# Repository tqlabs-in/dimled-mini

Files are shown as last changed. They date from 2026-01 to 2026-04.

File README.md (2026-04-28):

<p align="center">
  <a href="https://github.com/tqlabs-in/dimled-mini">
    <picture>
      <source srcset="assets/logo-dark.png" media="(prefers-color-scheme: dark)">
      <source srcset="assets/logo-light.png" media="(prefers-color-scheme: light)">
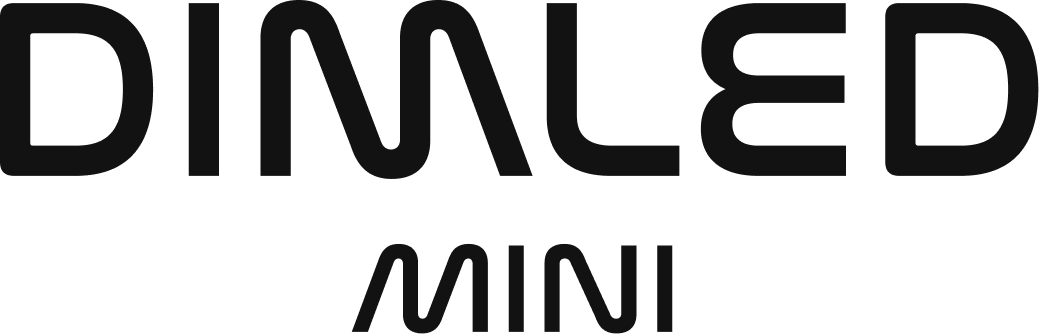
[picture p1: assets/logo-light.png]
DimLED Mini logo
      
    </picture>
  </a>
</p>

<p align="center"><q style="font-style: italic; font-weight: bold;"> Open Source PWM LED Dimmer powered by ESPHome </q></p>
<p align="center">
  
  
</p>

## 😎 Product Photography

<p align="center">
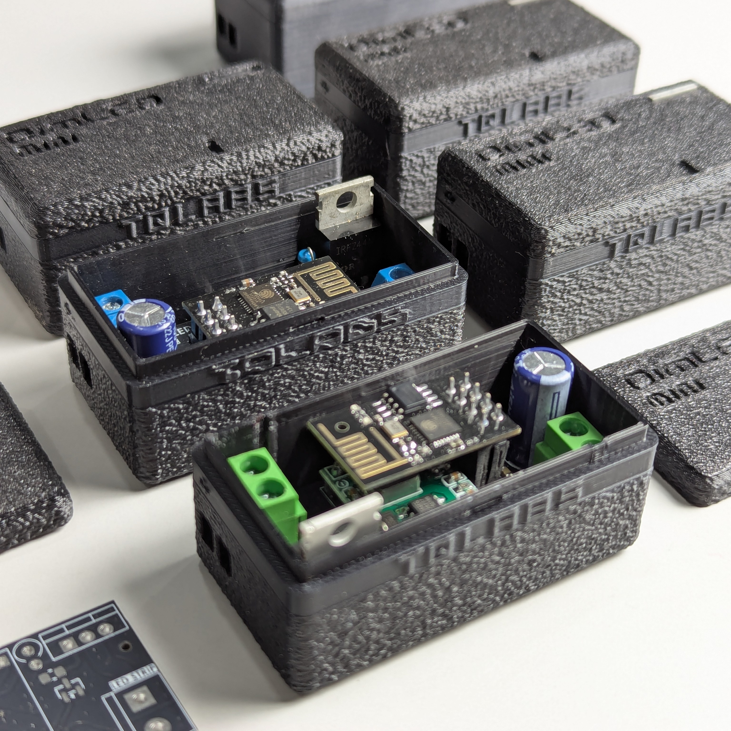
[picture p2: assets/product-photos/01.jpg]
Product Image 1
  
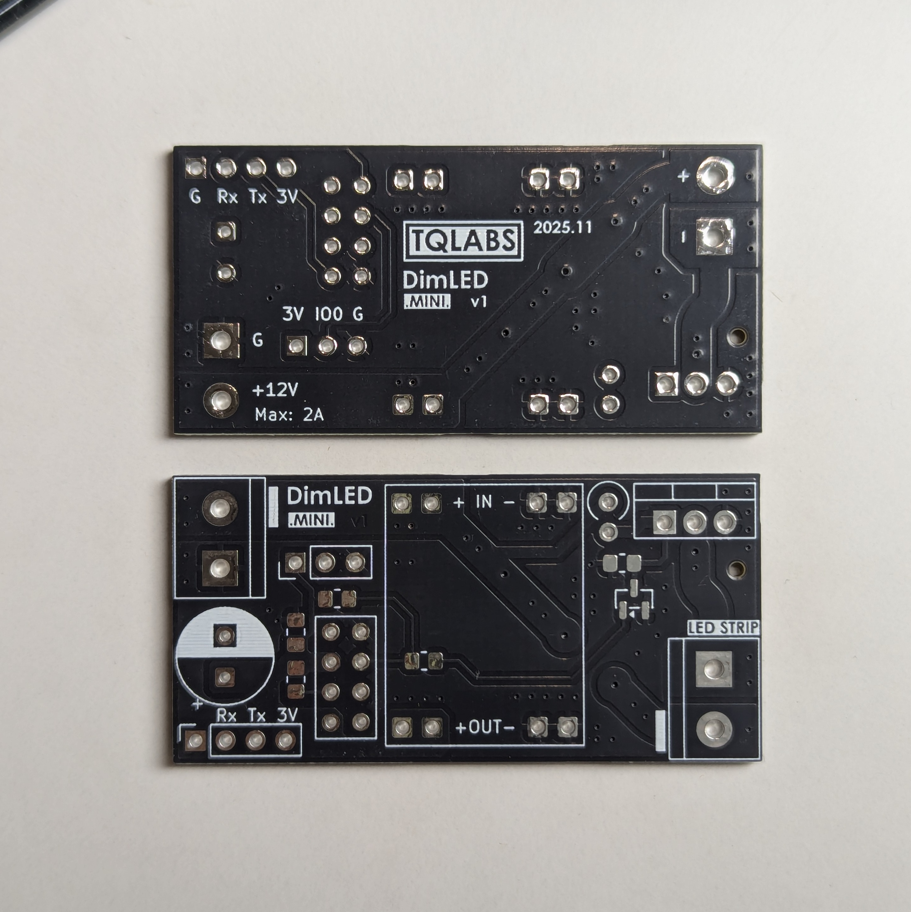
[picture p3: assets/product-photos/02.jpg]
Product Image 2
  
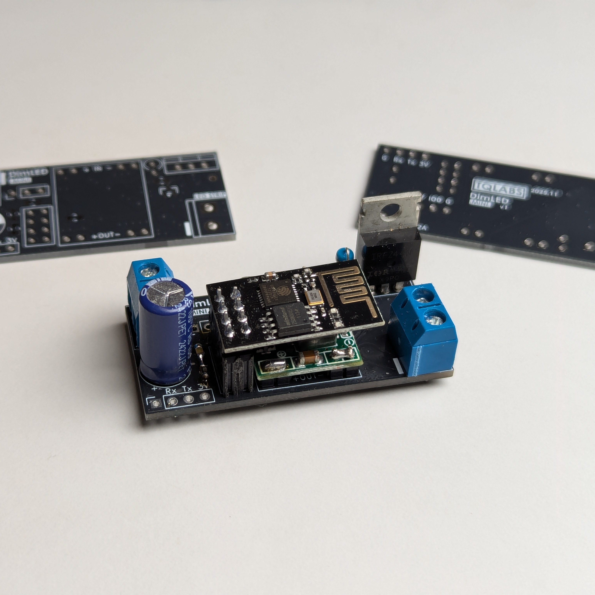
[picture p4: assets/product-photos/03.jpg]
Product Image 3
  
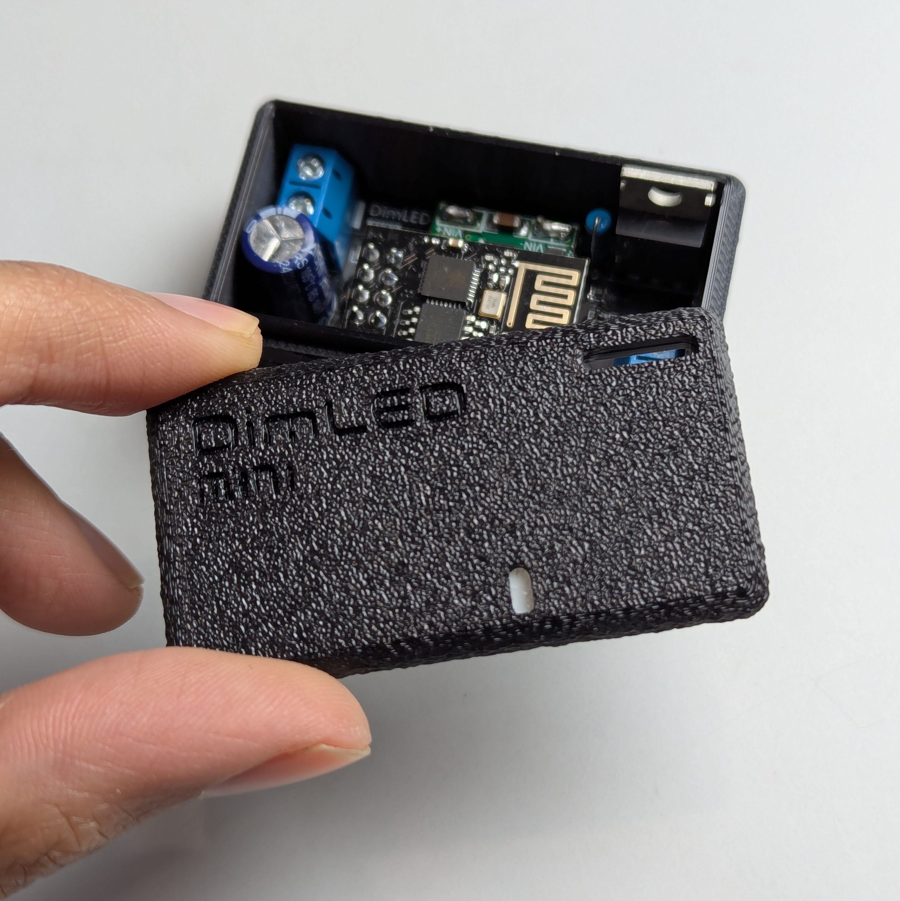
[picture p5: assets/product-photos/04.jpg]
Product Image 4
  
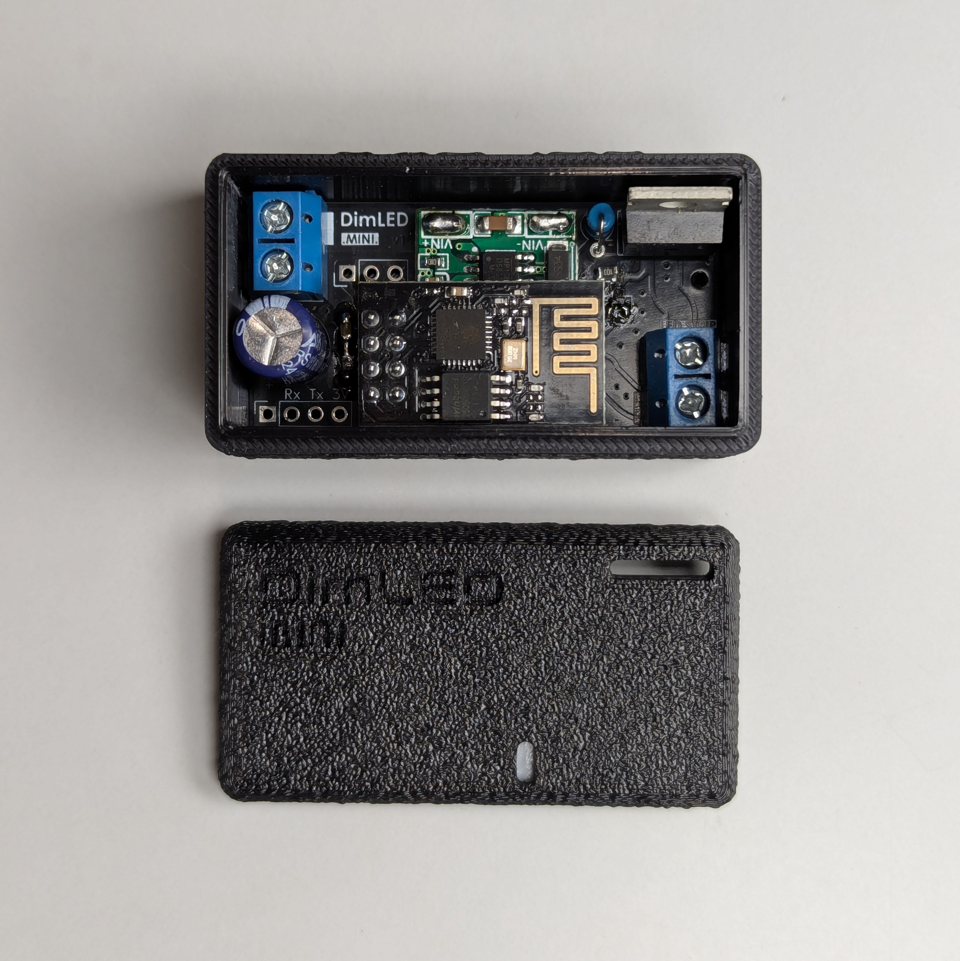
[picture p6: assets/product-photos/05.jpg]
Product Image 5
  
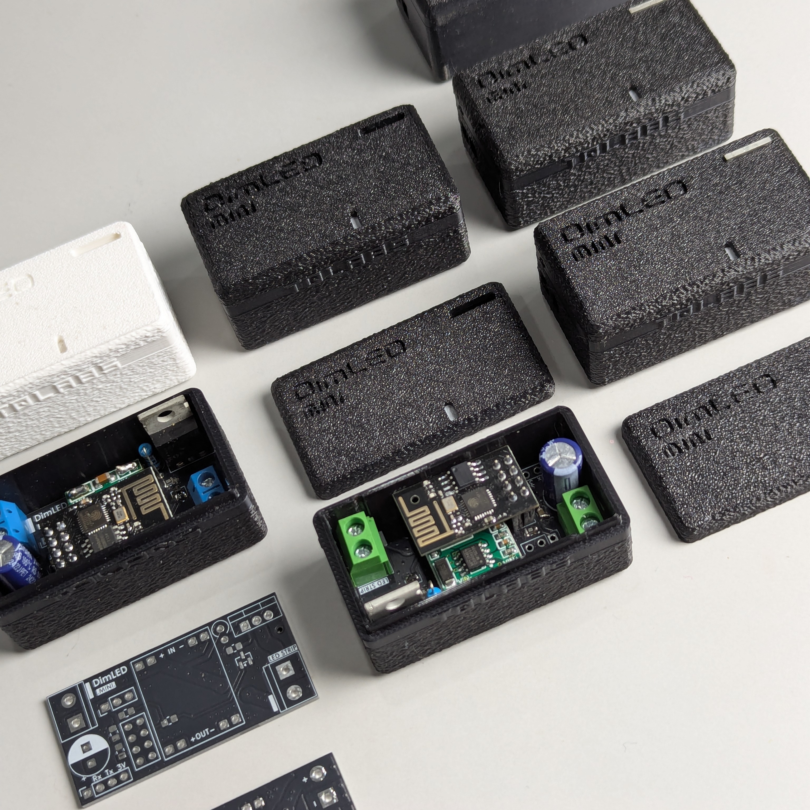
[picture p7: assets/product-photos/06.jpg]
Product Image 6
  
</p>

## 🎰 PCB Renders

<p align="center">
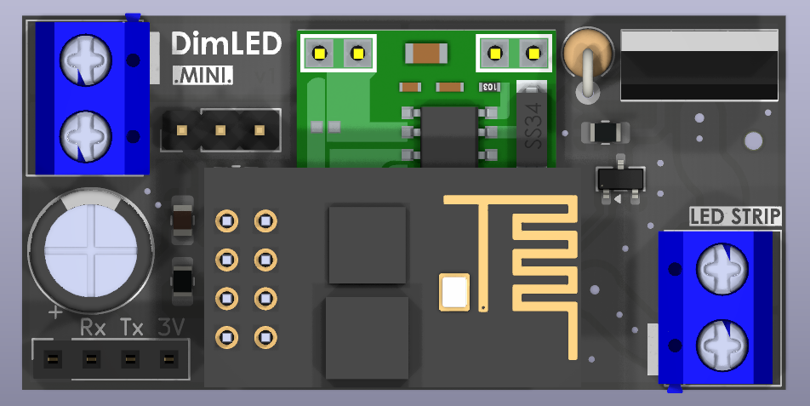
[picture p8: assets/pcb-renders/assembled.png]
PCB Render
  
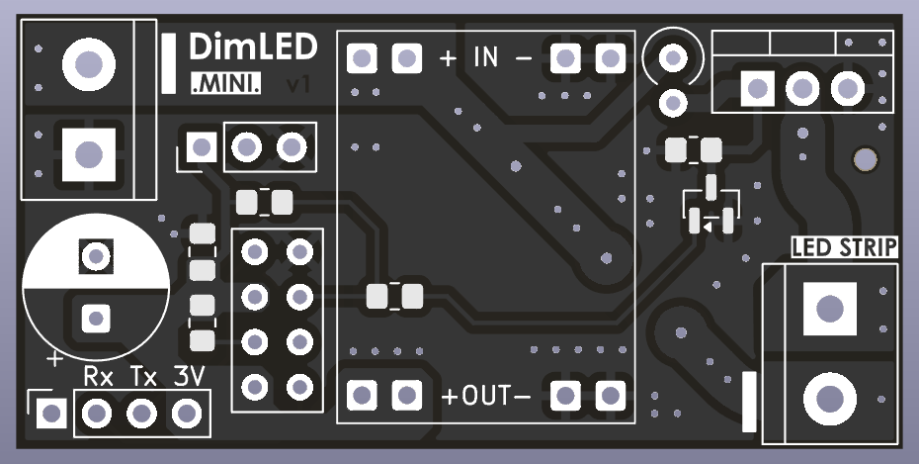
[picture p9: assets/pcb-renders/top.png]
PCB Top Layer
  
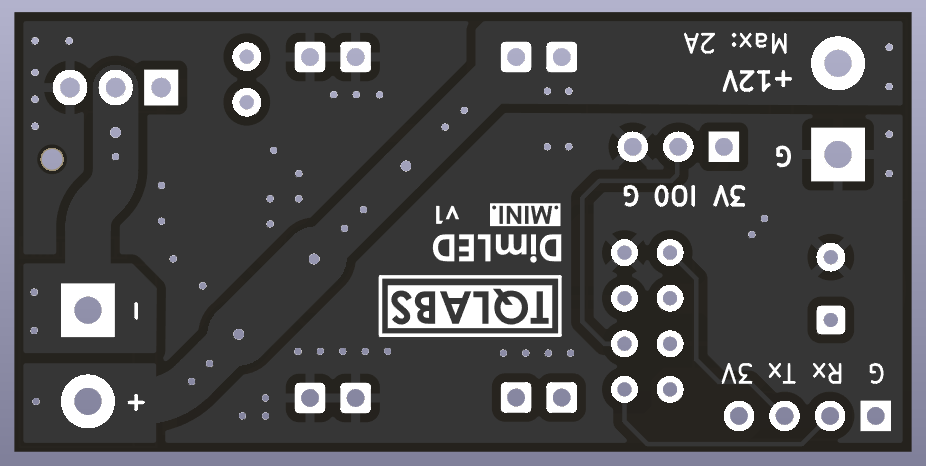
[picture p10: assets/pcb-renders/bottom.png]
PCB Bottom Layer
  
</p>

## 🧲 Useful Links

- [Web Flasher](https://tqlabs-in.github.io/dimled-mini/)
- [BOM](https://htmlpreview.github.io/?https://raw.githubusercontent.com/tqlabs-in/dimled-mini/main/pcb/bom/ibom.html)

## 🍀 Show your Support

Give a ⭐️ if this project helped you or you find it interesting!

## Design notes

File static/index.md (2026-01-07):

# DimLED Mini

A simple led dimmer based on ESP-01 Module powered by esphome firmware.

# Installation

You can use the button below to install the pre-built firmware directly to your device via USB from the browser.

<esp-web-install-button manifest="firmware/dimled-mini.manifest.json"></esp-web-install-button>

<script type="module" src="https://unpkg.com/esp-web-tools@10/dist/web/install-button.js?module"></script>

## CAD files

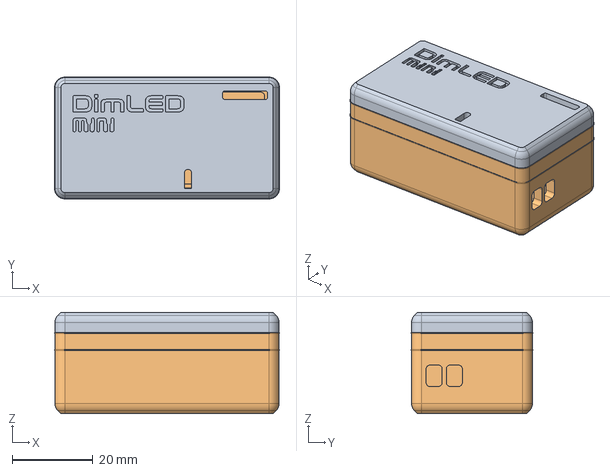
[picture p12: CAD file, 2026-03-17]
enclosure/v3/DimLEDmini Case.FCStd
55.6 x 30.1 x 25.0 mm
Part B
Part A - Ribbed

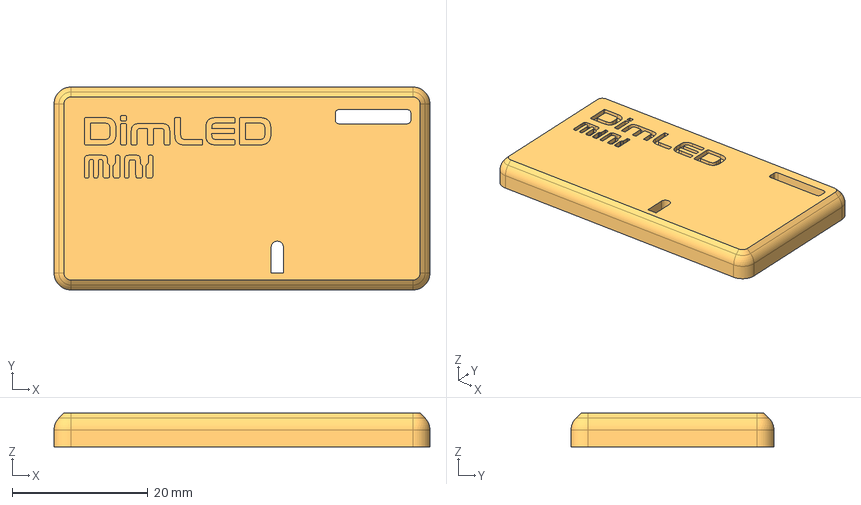
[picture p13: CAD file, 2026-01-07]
enclosure/v3/models/DimLEDmini Case-Part B.step
55.4 x 29.9 x 5.00 mm

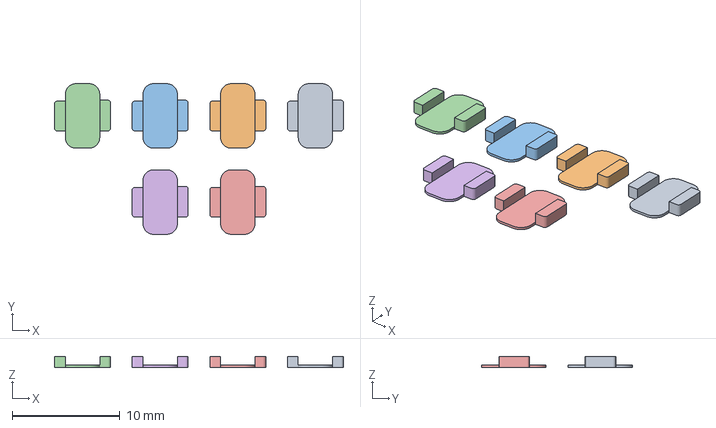
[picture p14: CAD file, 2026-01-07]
enclosure/v3/printing/diffuser.petg.orca.dev.3mf
26.8 x 14.0 x 1.00 mm
DimLEDmini Case-Part B - LED Cover.step x 6

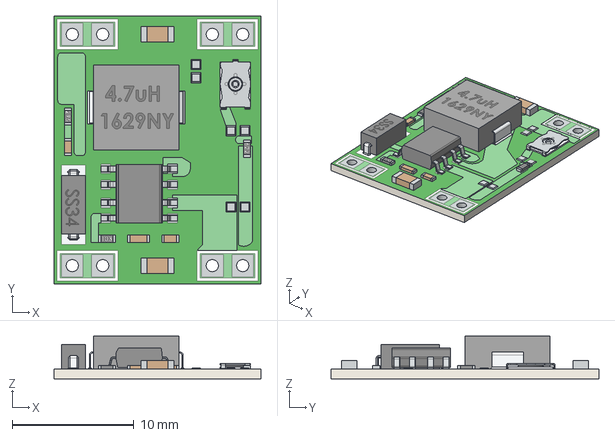
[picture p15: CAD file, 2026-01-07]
pcb/3dmodels/MP1584_Module.step
17.0 x 22.0 x 3.50 mm

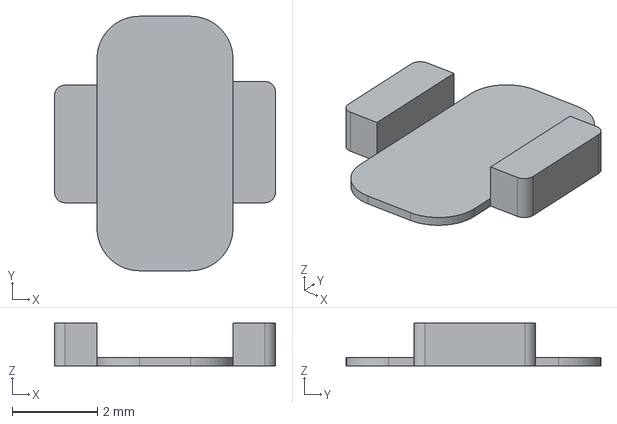
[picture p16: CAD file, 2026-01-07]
enclosure/v3/models/DimLEDmini Case-Part B - LED Cover.step
5.20 x 5.99 x 1.00 mm

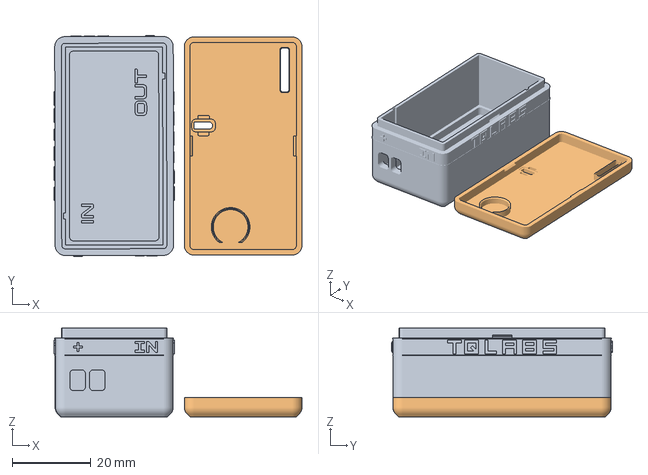
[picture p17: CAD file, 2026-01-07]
enclosure/v3/printing/case.pla+.orca.dev.3mf
63.0 x 56.0 x 22.6 mm
Lid

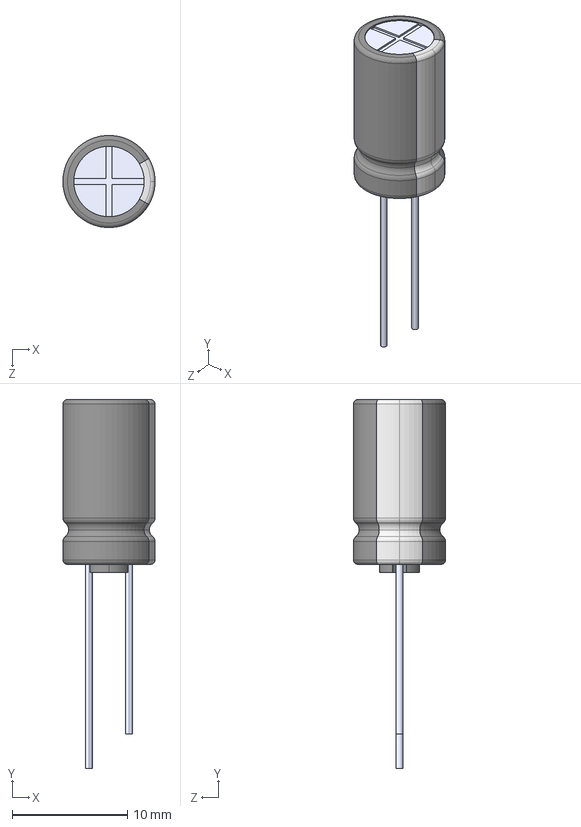
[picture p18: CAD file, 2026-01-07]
pcb/3dmodels/C_Radial_D8.0mm_H15.0mm_P3.50mm.step
8.00 x 32.0 x 7.99 mm

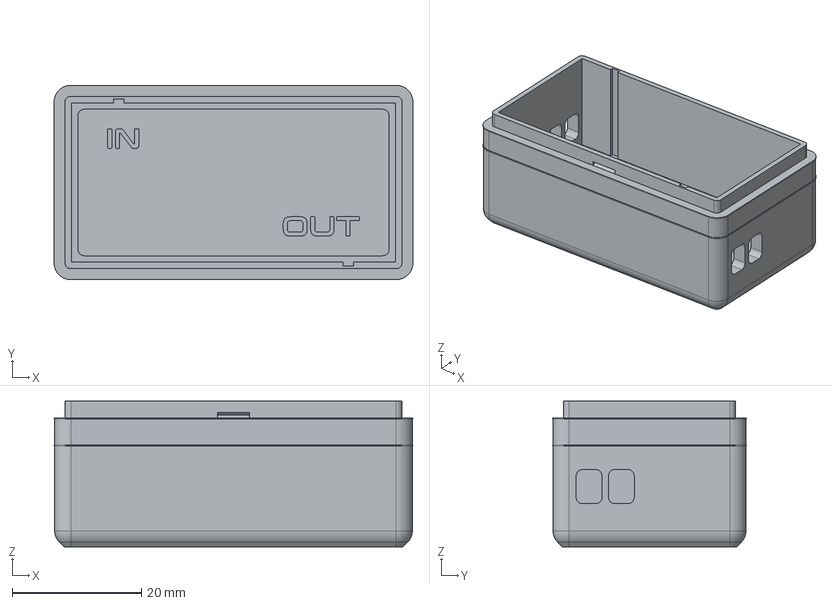
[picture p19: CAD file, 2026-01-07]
enclosure/v3/models/DimLEDmini Case-Part A - Ribbed.step
55.6 x 30.1 x 22.6 mm

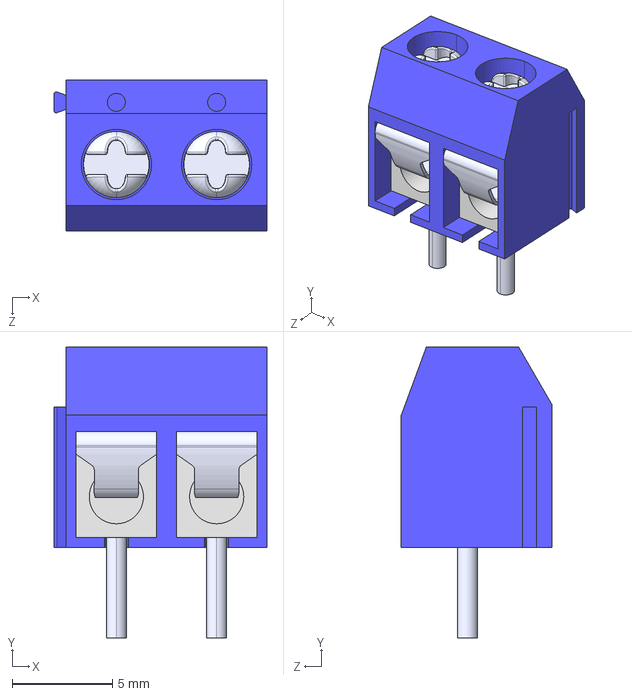
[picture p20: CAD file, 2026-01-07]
pcb/3dmodels/TerminalBlock_KF301-2P_P5.08mm.step
10.6 x 14.5 x 7.50 mm

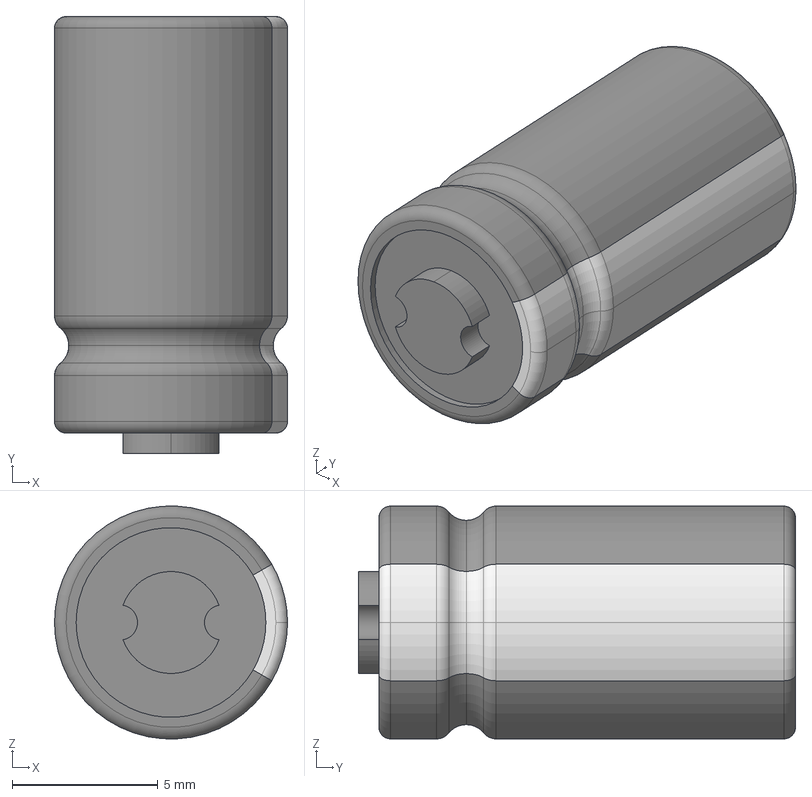
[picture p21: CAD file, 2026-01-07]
pcb/3dmodels/C_Radial_D8.0mm_H15.0mm_P3.50mm_No_Legs.step
8.00 x 15.0 x 7.99 mm
EEUEB1A471
EEUEB1A472
EEUEB1A475

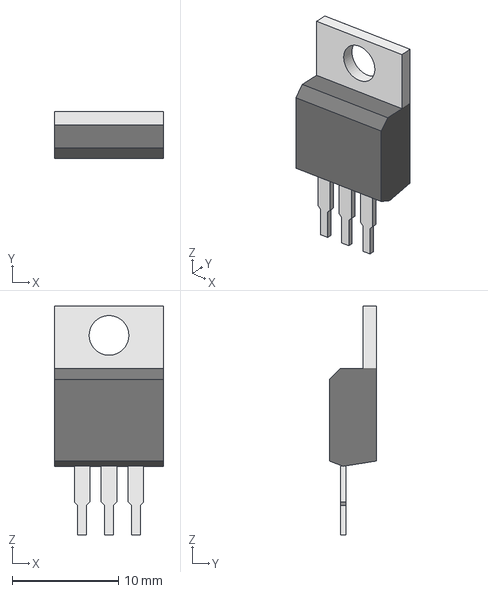
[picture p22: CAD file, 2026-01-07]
pcb/3dmodels/TO-220-3_Vertical_Trimmed_Legs.step
10.2 x 4.46 x 21.6 mm

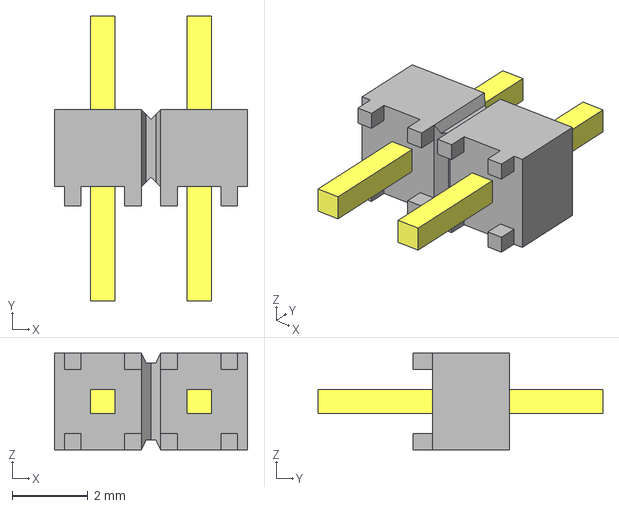
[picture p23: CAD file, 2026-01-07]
pcb/3dmodels/PinHeader_1x02_P2.54mm_L7.50mm_Vertical.step
5.08 x 7.50 x 2.54 mm
MTSW-102-07-T-S-150_body

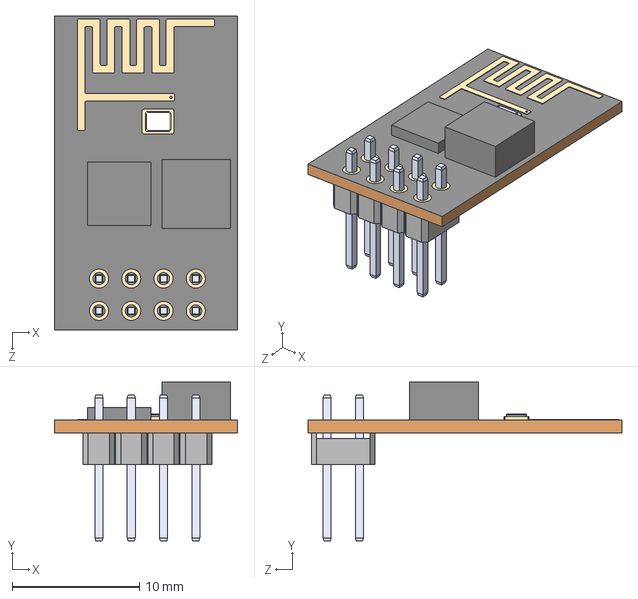
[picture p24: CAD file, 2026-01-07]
pcb/3dmodels/ESP8266-01_ESP-01.step
14.4 x 12.5 x 24.7 mm

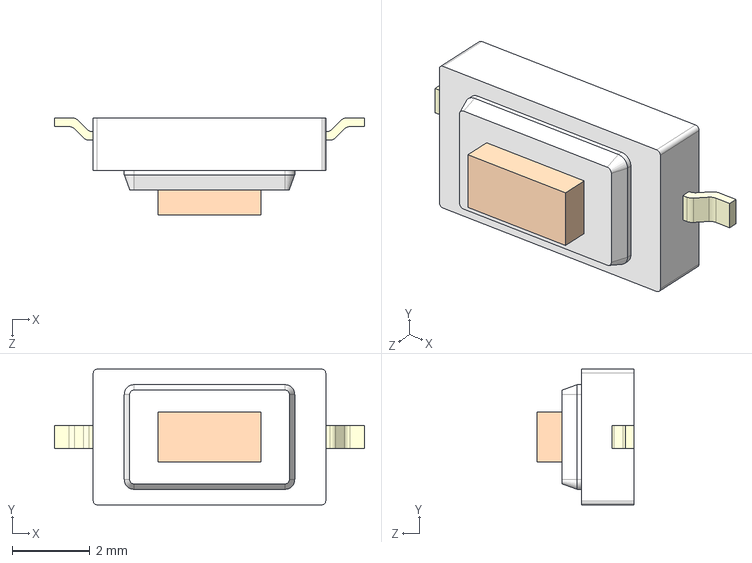
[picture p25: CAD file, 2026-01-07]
pcb/3dmodels/SW_Push_SPST_L6.40mm_W3.80mm_H2.5mm.step
8.00 x 3.50 x 2.50 mm

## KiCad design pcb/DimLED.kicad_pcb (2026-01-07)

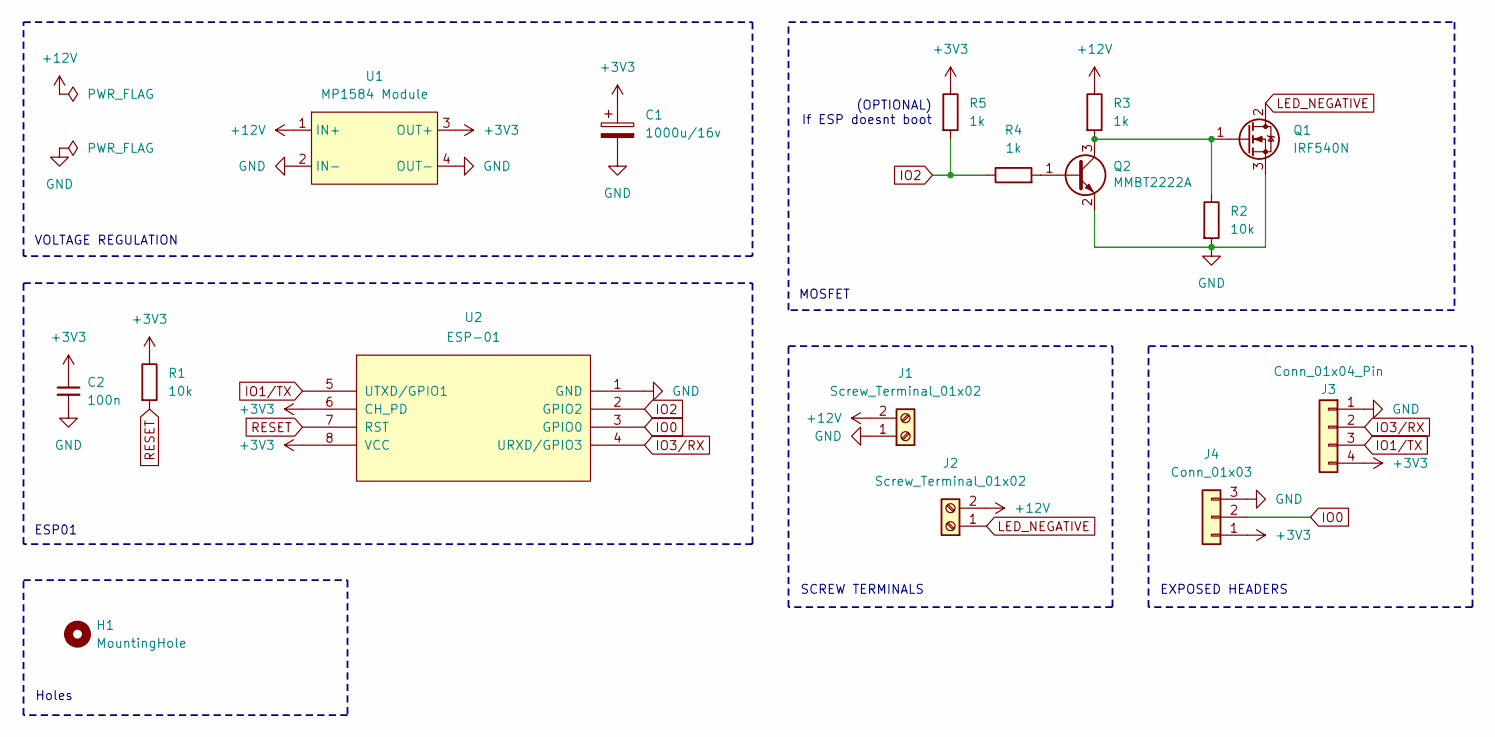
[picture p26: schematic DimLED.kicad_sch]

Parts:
C1: 1000u/16v; CP_Radial_D8.0mm_P3.50mm
C2: 100n; C_0805_2012Metric_Pad1.18x1.45mm_HandSolder
H1: MountingHole; ToolingHole_1.152mm
J1, J2: Screw_Terminal_01x02; TerminalBlock_bornier-2_P5.08mm
J3: Conn_01x04_Pin; PinSocket_1x04_P2.54mm_Vertical
J4: Conn_01x03; PinHeader_1x03_P2.54mm_Vertical
Q1: IRF540N; TO-220-3_Vertical
Q2: MMBT2222A; SOT-23
R1, R2: 10k; R_0805_2012Metric_Pad1.20x1.40mm_HandSolder
R3: 1k; R_Axial_DIN0309_L9.0mm_D3.2mm_P2.54mm_Vertical
R4, R5: 1k; R_0805_2012Metric_Pad1.20x1.40mm_HandSolder
U1: MP1584 Module; MP1584-Module_22.1x16.8mm_THT
U2: ESP-01; ESP-01_With_Headers

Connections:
+3V3: C1.1, C2.1, J3.4, J4.1, R1.1, R5.1, U1.3 (OUT+), U2.6 (CH_PD), U2.8 (VCC)
+12V: J1.2, J2.2, R3.1, U1.1 (IN+)
GND: C1.2, C2.2, J1.1, J3.1, J4.3, Q1.3 (S), Q2.2 (E), R2.2, U1.2 (IN-), U1.4 (OUT-), U2.1 (GND)
IO0: J4.2, U2.3 (GPIO0)
IO1/TX: J3.3, U2.5 (UTXD/GPIO1)
IO2: R4.1, R5.2, U2.2 (GPIO2)
IO3/RX: J3.2, U2.4 (URXD/GPIO3)
LED_NEGATIVE: J2.1, Q1.2 (D)
unnamed: Q1.1 (G), Q2.3 (C), R2.1, R3.2
unnamed: Q2.1 (B), R4.2
RESET: R1.2, U2.7 (RST)

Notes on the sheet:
Holes
(OPTIONAL) If ESP doesnt boot
ESP01
VOLTAGE REGULATION
EXPOSED HEADERS
MOSFET
SCREW TERMINALS

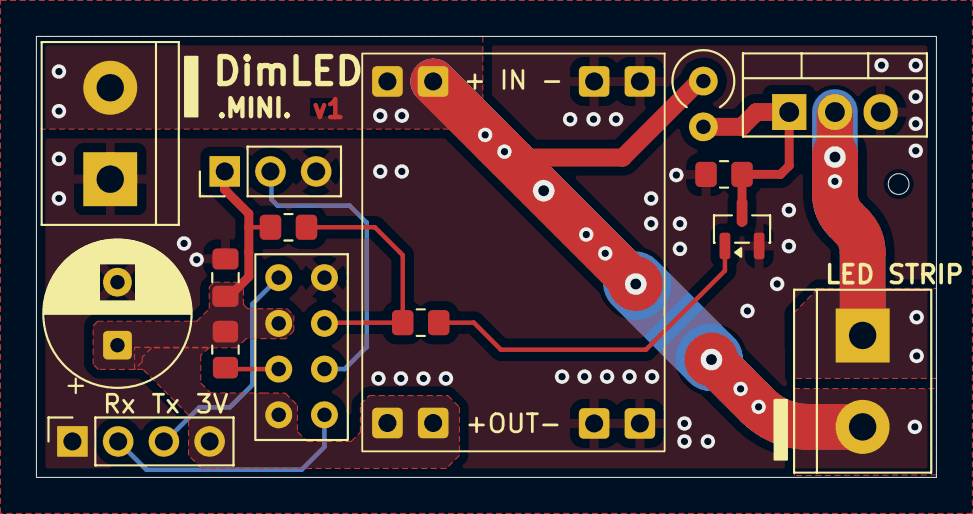
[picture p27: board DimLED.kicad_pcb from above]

Board: 2 copper layers, 50.0 x 24.5 mm, 16 parts (0 on the bottom side), 11 nets.

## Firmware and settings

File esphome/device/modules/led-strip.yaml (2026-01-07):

defaults:
  led_strip_id: led_strip

globals:
  - id: saved_is_on
    type: bool
    restore_value: yes
    initial_value: "false"

  - id: saved_brightness
    type: float
    restore_value: yes
    initial_value: "0.5"

esphome:
  on_boot:
    - priority: -100
      then:
        - script.execute: restore_state

output:
  - platform: esp8266_pwm
    id: led_strip_output
    pin:
      number: GPIO2
      inverted: true
    frequency: 1000Hz
    zero_means_zero: true

light:
  - platform: monochromatic
    output: led_strip_output
    id: $led_strip_id
    name: LED Strip
    icon: mdi:led-strip-variant
    restore_mode: ALWAYS_OFF
    gamma_correct: 1.8
    default_transition_length: 0.75s
    effects:
      - flicker:
      - pulse:
      - pulse:
          name: "Fast Pulse"
          transition_length: 0.5s
          update_interval: 0.5s
          min_brightness: 0%
          max_brightness: 100%
      - pulse:
          name: "Slow Pulse"
          update_interval: 2s
      - pulse:
          name: "Faded Glow Pulse"
          transition_length:
            on_length: 1s
            off_length: 2s
          update_interval: 4s
          min_brightness: 20%
          max_brightness: 40%

button:
  - platform: template
    name: "Save State"
    icon: mdi:content-save-move
    entity_category: config
    on_press:
      - lambda: |-
          id(saved_is_on) = id($led_strip_id).current_values.is_on();
          id(saved_brightness) = id($led_strip_id).current_values.get_brightness();
      - script.execute: indicate_save
      - script.execute: sync_preferences

  - platform: template
    name: "Restore State"
    icon: mdi:restore
    entity_category: config
    on_press:
      - script.execute: restore_state

script:
  - id: restore_state
    then:
      - light.control:
          id: $led_strip_id
          brightness: !lambda "return id(saved_brightness);"
          state: !lambda "return id(saved_is_on) == true;"

  - id: indicate_save
    mode: restart
    then:
      - if:
          condition:
            light.is_on: $led_strip_id
          then:
            - light.turn_on: $led_strip_id
            - delay: 0.75s
            - light.turn_off: $led_strip_id
            - delay: 0.75s
            - light.turn_on: $led_strip_id
          else:
            - light.turn_off: $led_strip_id
            - delay: 0.75s
            - light.turn_on:
                id: led_strip
                brightness: 0.1
            - delay: 0.75s
            - light.control:
                id: led_strip
                brightness: !lambda "return id(saved_brightness);"
                state: false

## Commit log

2026-01-07 feat: init
    [C_Radial_D8.0mm_H15.0mm_P3.50mm.step, C_Radial_D8.0mm_H15.0mm_P3.50mm_No_Legs.step, DimLED.kicad_pcb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]
2026-03-17 chore: update case
    [DimLEDmini Case.FCStd]
